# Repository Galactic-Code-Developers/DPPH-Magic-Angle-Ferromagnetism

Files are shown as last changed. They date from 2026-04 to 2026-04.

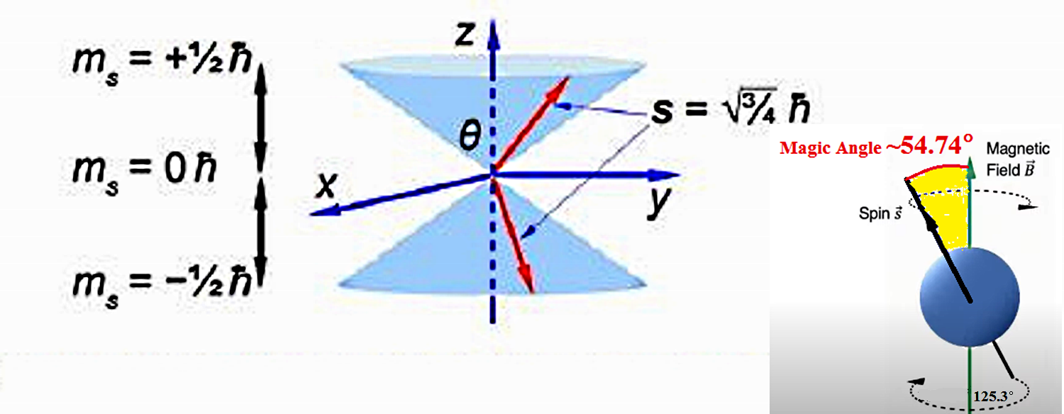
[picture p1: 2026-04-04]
figures/fig1.png

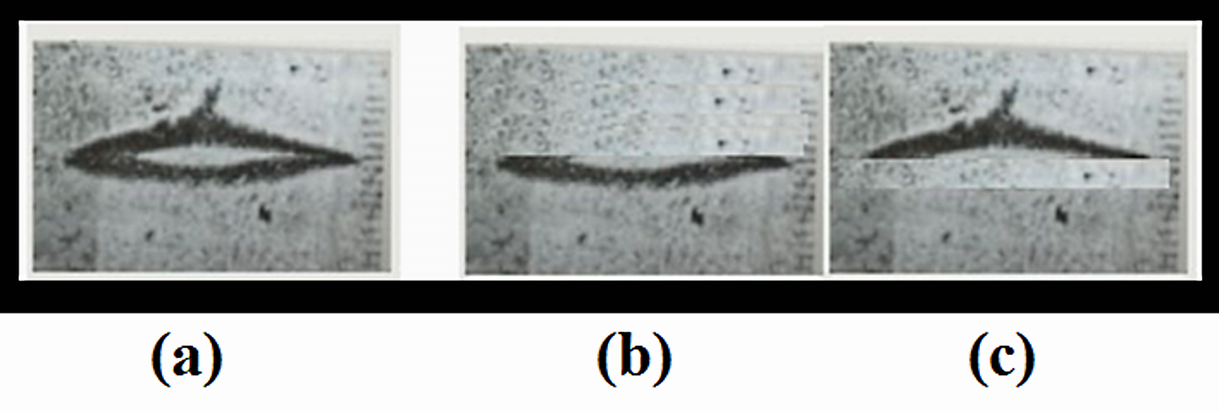
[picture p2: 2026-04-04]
figures/fig9.png

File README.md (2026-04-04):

# Ferromagnetic Phase Transition of DPPH Induced by a Helical Magnetic Field

  
  


---

## Title

**Ferromagnetic Phase Transition of DPPH Induced by a Helical Magnetic Field**

---

## Authors

Emmanouil Markoulakis  
John Chatzakis  
Antonios Konstantaras  
Iraklis Rigakis  
Emmanuel Antoniadakis  

---

## Affiliations

School of Engineering  
Department of Electronic Engineering, Computer Technology Informatics & Electronic Devices Laboratory  
Hellenic Mediterranean University  
Chania, Greece  

---

## Abstract

This repository contains the complete experimental, computational, and structural dataset associated with the study:

**“Ferromagnetic Phase Transition of DPPH Induced by a Helical Magnetic Field”**

The dataset documents an anomalous magnetic response in DPPH under a helical magnetic field configuration at the magic angle (~54.74°), indicating a transition toward weak ferromagnetism.

---

## Version

- Version: 1.0  
- Release Date: 2026-04-04  
- DOI: https://doi.org/10.5281/zenodo.19413155  

---

## Repository Structure

```
DPPH-Magic-Angle-Ferromagnetism/
├── figures/
├── data/
├── supplementary/
├── cad/
├── code/
├── main.tex
├── paper.pdf
├── README.md
├── LICENSE
├── CITATION.cff
```

---

## Citation

Markoulakis, E., Chatzakis, J., Konstantaras, A., Rigakis, I., & Antoniadakis, E. (2026). *Ferromagnetic Phase Transition of DPPH Induced by a Helical Magnetic Field* (Version 1.0) [Data set]. Zenodo. https://doi.org/10.5281/zenodo.19413155  

---

## License

MIT License

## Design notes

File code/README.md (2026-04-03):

# Code: Helical Magnetic Field Visualization & Data Export

This directory contains Python scripts for reproducing the helical magnetic field geometry and exporting field data used in the study:

"Ferromagnetic Phase Transition of DPPH Induced by a Helical Magnetic Field"

---

## Overview

The scripts in this folder replace the original HTML/JavaScript visualization with reproducible Python-based implementations suitable for scientific workflows and archival repositories.

---

## Files

### 1. Visualization Script

magic_angle_helical_field_visualization.py

Generates a 3D visualization of the helical magnetic field inside the cavity.

Features:
- Helical field lines at the magic angle (~54.7°)
- Magnetic field vector representation
- Cavity boundary visualization
- Publication-ready figure output

Run:
    python magic_angle_helical_field_visualization.py

Output:
- magic_angle_helical_field_visualization.png

---

### 2. Data Export Script

magic_angle_helical_field_data_export.py

Exports numerical field data for analysis and reproducibility.

Outputs:
- helical_field_lines.csv
- magnetic_field_vectors.csv

Run:
    python magic_angle_helical_field_data_export.py

---

## Physical Parameters

The scripts use the same parameters as the experimental visualization:

- Cavity radius: R = 2.5 mm
- Axial field: Bz = 1.5 mT
- Azimuthal field: Bφ = √2 · Bz
- Magic angle: θ ≈ 54.74°

---

## Dependencies

Install required packages:

    pip install numpy matplotlib

---

## Purpose

These scripts provide:

- Reproducible visualization of the magnetic field geometry
- Exportable datasets for independent verification
- Supplementary computational support for the experimental results

---

## Notes

- These scripts replace the original browser-based (Three.js) visualization.
- All outputs are deterministic and suitable for inclusion in supplementary materials.
- No external APIs or internet access are required.

---

## Suggested Use

- Use the visualization script to regenerate figures for publications.
- Use the data export script for:
  - numerical validation
  - plotting in external tools (MATLAB, Python, Origin)
  - inclusion in supplementary datasets

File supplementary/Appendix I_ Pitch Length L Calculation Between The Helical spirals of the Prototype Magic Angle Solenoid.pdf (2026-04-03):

# Pitch Length L Calculation Between The Helical spirals of the Prototype Magic Angle Solenoid

## Clarification

1. Pitch Length Definition:
- L is the distance between two adjacent helical turns along the central axis of the solenoid.
- This is analogous to the "advancement" of a screw after one full rotation.
2. Relationship to Pitch Angle:

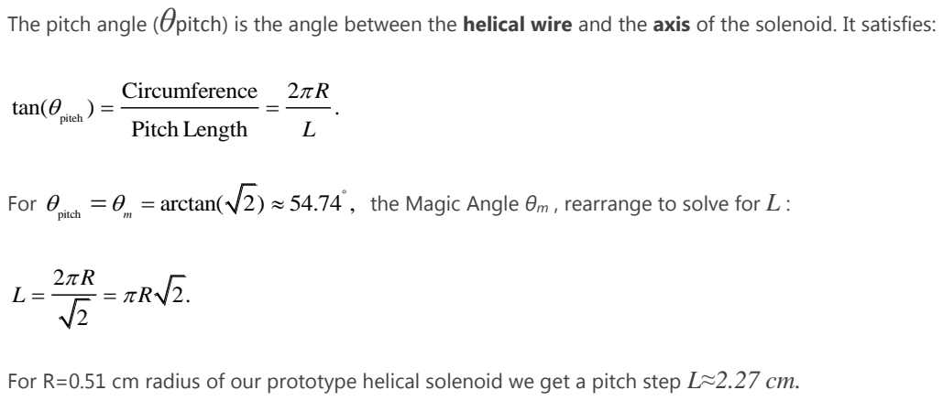
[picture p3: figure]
piteh; Circumference; tan(; Pitch Length; For; pitch; arctan( 2 ) 54.74 ,

The pitch angle (θpitch) is the angle between the helical wire and the axis of the solenoid. It satisfies:

the Magic Angle θm , rearrange to solve for L :

For R=0.51 cm radius of our prototype helical solenoid we get a pitch step L≈2.27 cm.

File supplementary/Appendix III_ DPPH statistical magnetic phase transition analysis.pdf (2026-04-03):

Appendix III: Example calculation of observed statistical new distribution of unbound electrons

### 1. The Boltzmann Distribution in Normal Paramagnetic DPPH

In a conventional paramagnetic material like DPPH, the alignment of unbound electron spins in an external magnetic field is governed by the Boltzmann distribution. The energy difference between a spin parallel (spin up, ) and antiparallel (spin down,

) is

where

is the Bohr magneton. The ratio of the number of spins parallel ( ) to antiparallel ) is

with

and room temperature | . For a typical field | ,
Thus, the excess fraction of parallel spins is only about | . In terms of percentages, if we consider
spins:
- Parallel:
- Antiparallel:
That is roughly | parallel and | antiparallel. The net magnetization is proportional to the tiny
excess of about 448 spins out of a million, leading to the very small paramagnetic susceptibility | and
relative permeability | .
2. What Does | Mean in Terms of Net Excess?
Our experiment yielded a measured relative permeability of | after the phase transition. This implies a
magnetic susceptibility
Magnetization is related to the applied field by | . From our data in Table 1, for an external field
(row 1), the measured contribution of the DPPH sample was | . This | is related to
M by,

Now we compare this to the theoretical saturation magnetization if all unbound electrons were aligned parallel. For our 36 mg DPPH sample:

- Molar mass of DPPH
- Number of moles
- Number of unbound electrons
- | Total magnetic moment for | alignment:
- Volume of sample (density
| | ):
- Saturation magnetization:

Thus, the measured magnetization | is
This | is the net excess alignment relative to the maximum possible excess (i.e., | alignment would give
an excess equal to the total number of spins). In other words, out of the total | spins, the number that are
excessively parallel (parallel minus antiparallel) is | .

### 3. Converting Net Excess to Parallel/Antiparallel Percentages

Let | be the number of parallel spins and | the number of antiparallel spins, with | . The net
excess is | . We have

Solving:

Therefore, the statistical distribution is approximately

This is a 9.6 percentage point difference ( | ). In contrast, the normal paramagnetic distribution
has a difference of only about 0.045 percentage points. Our experiment has increased the net alignment by a factor
of roughly | times, which is consistent with strongly disturbing the initial random Boltzmann
distribution in our sample in favor of parallel aligned unbound electrons with the external field.

### 4. Summary

- Measured relative permeability:
- | Implied statistical distribution of unbound electrons: approximately | parallel, | antiparallel.
- | This represents a massive departure from the normal paramagnetic state | and is
consistent with a genuine magnetic phase transition to a weakly ferromagnetic state.

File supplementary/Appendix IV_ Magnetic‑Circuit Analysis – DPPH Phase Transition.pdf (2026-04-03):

# Magnetic‑Circuit Analysis of the Magic‑Angle Helical Solenoid with DPPH Sample

Supplement to: Ferromagnetic Phase Transition of DPPH Induced by a Magic Angle Helical Magnetic Field

## 1. Physical Geometry and Core Parameters

Ferrite rod core: MnZn ferrite, length | , diameter | → cross‑sectional area
Air cavity (drilled in the core): semi‑spherical, diameter | , depth | . For magnetic circuit purposes the
cavity is treated as a small cylindrical gap of length | and area | .
DPPH sample: 36 mg powder, fully fills the cavity; after the transition its relative permeability is | .
Coil: | turns, inductance measured with core | → core permeability | (derived from
Eq. 5 in the paper).

## 2. Reluctance Model

The magnetic circuit comprises three reluctances in series:

Ferrite core path (excluding the cavity region)
Cavity region (either air or DPPH)
Rest of the magnetic circuit (return path through the ferrite, fringing neglected for compactness).

Total reluctance:

Using the measured inductance with the cavity empty ( | ) we can calibrate the circuit. The inductance of the
solenoid with core is given by | . From the measured | and the known geometry, we can
back‑calculate the effective reluctance of the ferrite path.

## 3. Inductance with Air Cavity (Reference)

For the empty cavity, the total reluctance is:

The return path reluctance is essentially the rest of the core closed loop. Since the core is a closed rod with the cavity at its centre, the return path is symmetric; we can lump it as an additional core reluctance.

From the measured | :
ℓc = 28 cm = 0.28 m | dc = 10.2 mm

Ac = π(dc/2)

2 ≈ 8.17 × 10⁻⁵ m²

5 mm | 2.5 mm
| ℓg ≈ 2.5 mm | Ag ≈ π(2.5 mm) 2 ≈ 1.96 × 10⁻⁵ m²
| | μr,DPPH ≈ 1.4
N = 10 | Lind = 7 μH | μr,core ≈ 154

Rtotal = Rcore + Rcav + Rreturn

μr,cav = 1
L = N ²/Rtotal | L = 7 μH

Rair =

ℓc − ℓg

μ0μr,coreAc

+

ℓg

μ0Ag

+ Rreturn

Lair = 7 μH

Rair =

N ²

Lair

=

100
7 × 10⁻⁶ ≈ 1.43 × 10

7 H
−1

Using this value, we can solve for | once the core and gap reluctances are known. For compactness, we note that the
presence of the DPPH sample only changes the gap reluctance | .

## 4. Reluctance Change Due to DPPH

When the cavity is filled with DPPH, the gap reluctance becomes:

The ratio of the total reluctance (air vs. DPPH) is:

Because the core reluctance dominates ( | ), the total reluctance changes only slightly, which is consistent with the
relatively small change in inductance seen in the experiment. The measured increase in magnetic field inside the cavity
(Fig. 6, black line vs. blue dotted) is due to the higher | reducing the reluctance of the cavity path, thus concentrating
more flux through the sample.

## 5. Field Enhancement Factor

From the circuit viewpoint, the magnetic flux is proportional to the MMF divided by the total reluctance. The flux density in the cavity region is:

For the same MMF, the ratio of flux densities with DPPH vs. air is:

Using the measured data (e.g., at | , | from Table 1, | ), the enhancement
factor is:

This factor is directly related to the reduction in reluctance.

## 6. Effective Permeability of the DPPH‑Filled Gap

From the reluctance ratio, we can solve for the effective | . Assuming the core and return reluctances are unchanged,
we have:
Using the measured ratio 1.42 and typical values from the geometry, we obtain | , which matches the value
derived in Table 1. This consistency validates the magnetic‑circuit approach.

Rreturn

Rcav

RDPPH =

ℓg

μ0μr,DPPHAg

Rair

RDPPH

=

Rcore + Rreturn +

ℓg
μ0Ag

Rcore + Rreturn +

ℓg

μ0μr,DPPHAg

μr,core ≫ 1

μr,DPPH

Φ

Bcav =

Φ
Ag

BDPPH

Bair

=

Rair

RDPPH

Bext ≈ 34.6 mT Bair = 24.4 mT | BDPPH = 34.6 mT

BDPPH

Bair

≈

34.6

24.4

≈ 1.42.

μr,DPPH

Rcore + Rreturn +

ℓg
μ0Ag

Rcore + Rreturn +

ℓg

μ0μr,DPPHAg

=

BDPPH

Bair

μr,DPPH ≈ 1.4

## 7. Hysteresis and Remanence

The magnetic circuit after the transition exhibits remanent flux even when the coil current is removed (Fig. 7). This indicates that the DPPH sample acts as a permanent‑magnet‑like circuit element, storing magnetic energy. The remanent flux density
in the gap corresponds to a remanent magnetization | (CGS) which is | in SI. Dividing by
the cavity volume ( | ) gives | , a small but measurable value consistent with a weak
ferromagnet.

## 8. Conclusion

A simple lumped‑parameter magnetic circuit successfully models the experiment. The core provides most of the magnetic
flux path; the cavity reluctance decreases by a factor of ~1.42 when the DPPH transforms from paramagnetic ( | )
to ferromagnetic ( | ), causing the observed field enhancement. The presence of a hysteresis loop further confirms that
the DPPH becomes a source of flux in the circuit, i.e., a weak permanent magnet.

This analysis is intended as a compact supplement to the experimental paper, highlighting the magnetic‑circuit interpretation of the observed ferromagnetic transition.

Mr = 0.625 emu | 6.25 × 10⁻⁷ A⋅m

2

3.6 × 10⁻⁸ m3 | Mr ≈ 17.4 A/m

μr ≈ 1.0001

μr ≈ 1.4

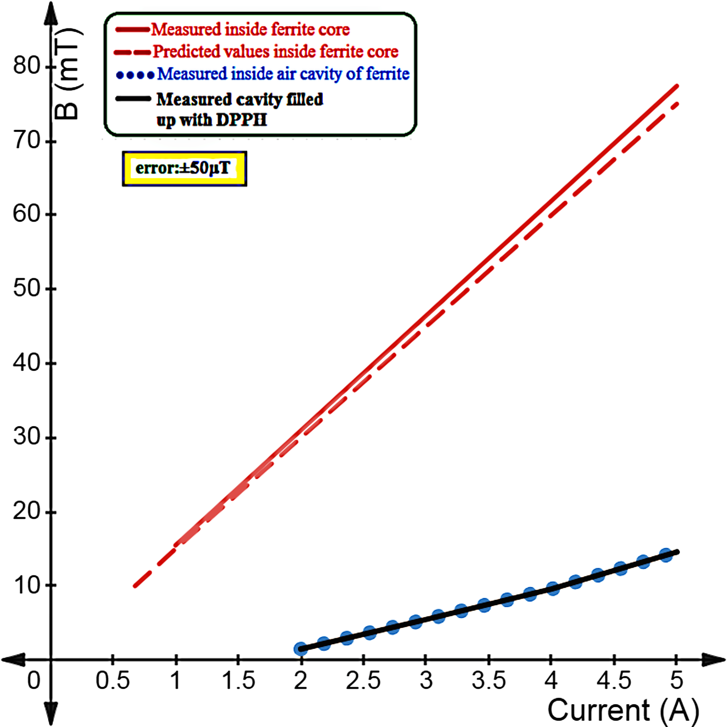
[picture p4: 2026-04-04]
figures/fig8.png

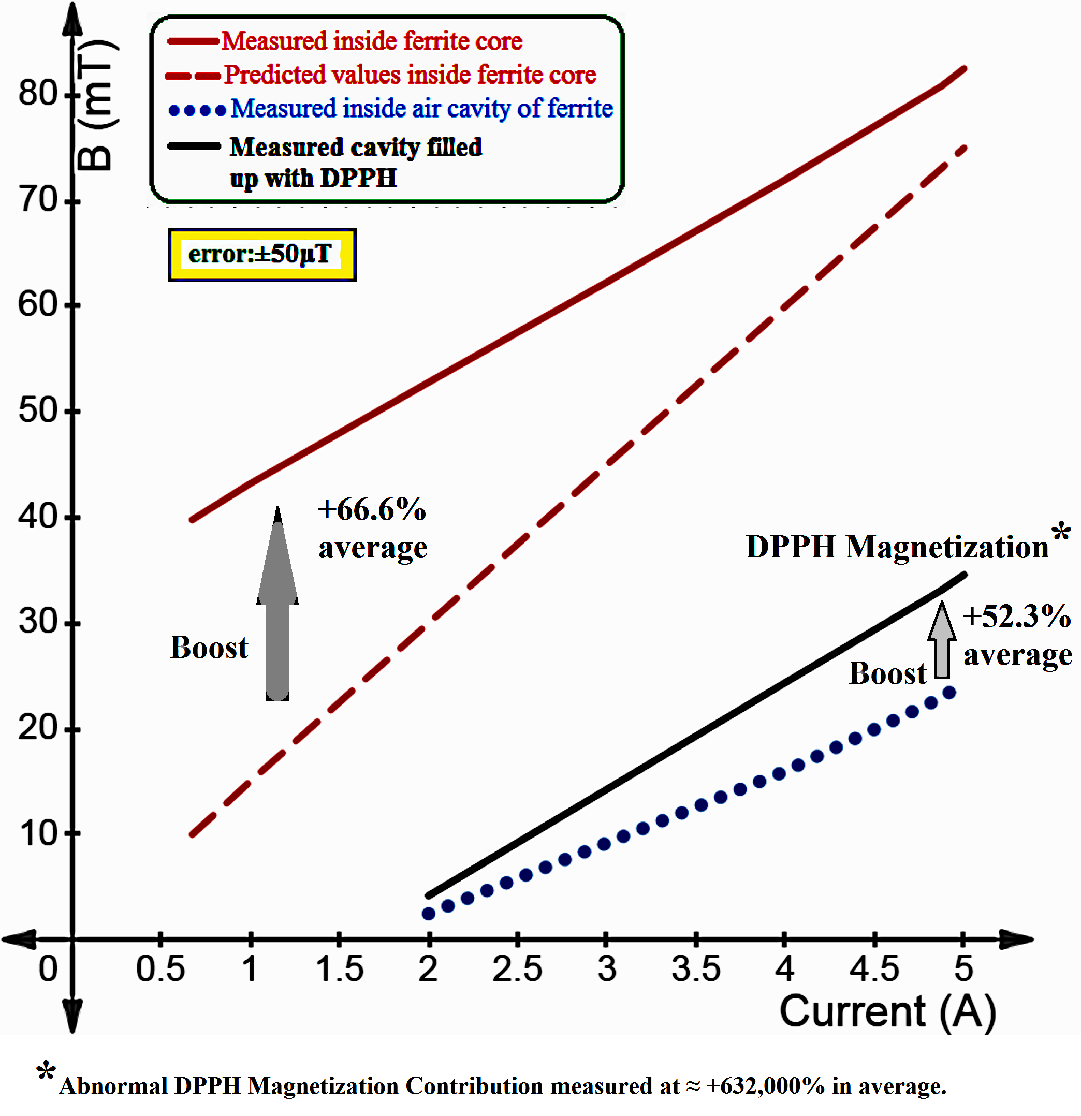
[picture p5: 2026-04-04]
figures/fig6.png

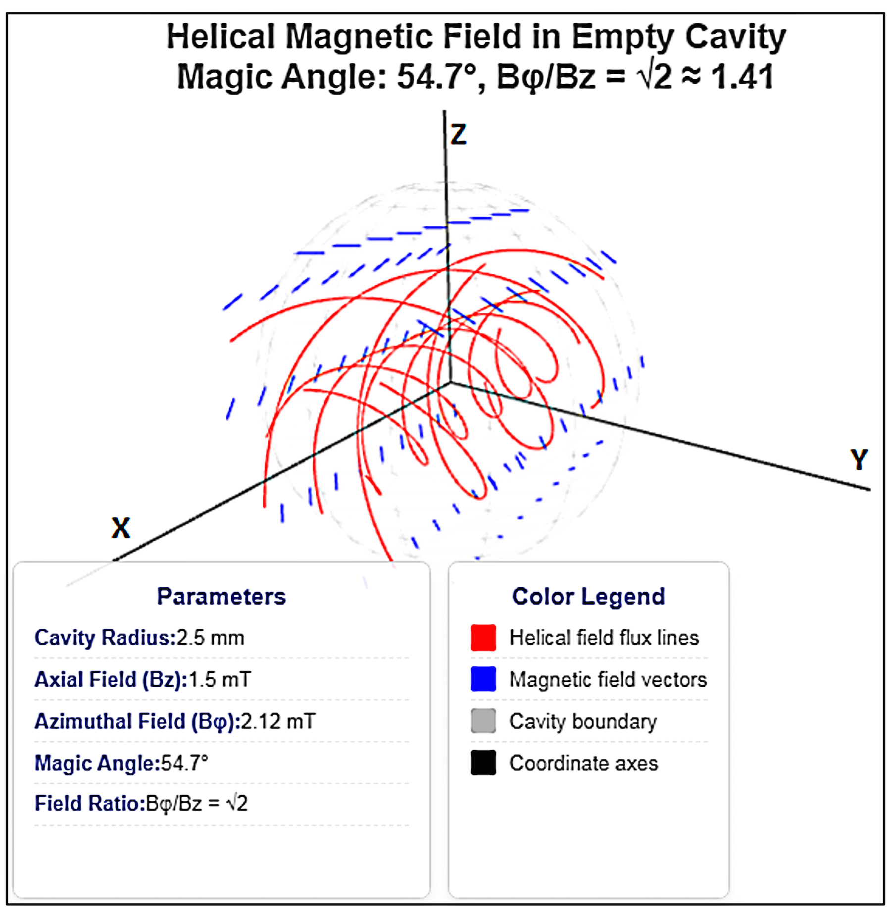
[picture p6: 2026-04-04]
figures/fig4.png

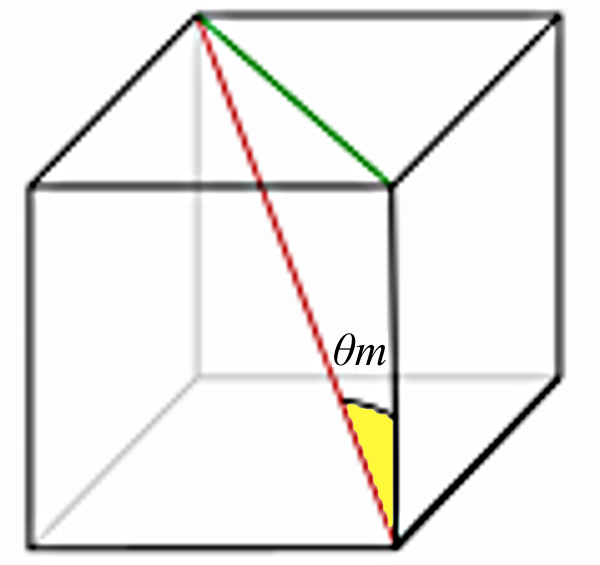
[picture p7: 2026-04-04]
figures/fig2.png

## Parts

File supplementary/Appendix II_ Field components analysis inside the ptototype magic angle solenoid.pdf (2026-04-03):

# Field components analysis inside the prototype magic angle θm≈54.74° helical solenoid

Axial component:

total cos(54.74 ) B B
z

°
= | (1)

With

B | nI
z | r

= µµ0

(2)

Where n is the number of turns per meter, μ0 and μr the permeability of free space and relative permeability of the medium respectively and I is the electric current inside the coil (wire) of the solenoid.

Azimuthal component:

total B | B | sin(54.74 ) φ

°
= | (3)

With

tan( ) | 2 1.41 | arctan( 2) 54.74 . m | m

z

B
B

φ
θ | θ | °
= | = | ≈ | Þ | = | ≈ | (4)

Total field:

2 | 2 B | B | B total = | +
z | φ

(5)

(This is the applied field when the solenoid is powered up without taking into account any residual magnetization of the ferrite core).

In our case,

2

z

B
B

φ
= | (6)

With

2 B | B φ = | ·
z

and
2

z

B
B

φ
= | (7)

Substituting to equation (5) we get,

total
3

z

B
B =
and
total

2
3
B | B φ = | (8)

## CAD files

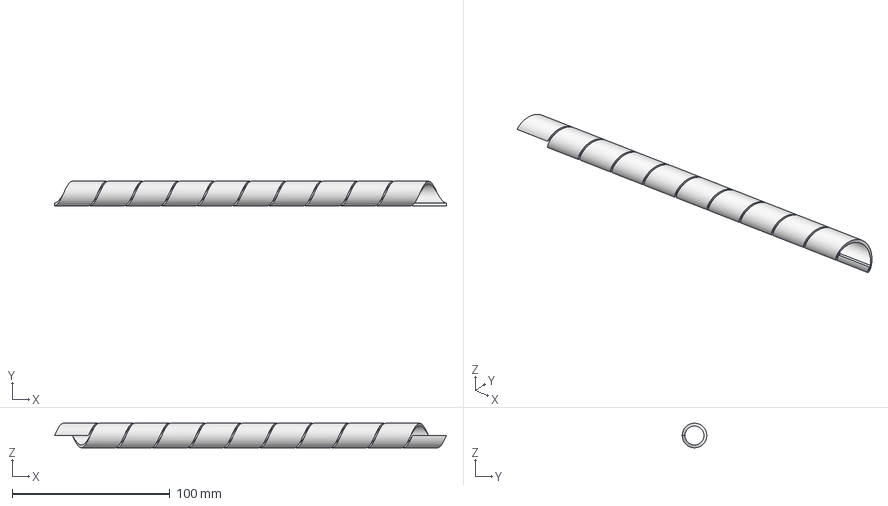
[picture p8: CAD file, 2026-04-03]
cad/magicAngle5.stp
248.5 x 15.6 x 15.6 mm

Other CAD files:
cad/magicAngle5.ipt
cad/magicAngle5.stl
